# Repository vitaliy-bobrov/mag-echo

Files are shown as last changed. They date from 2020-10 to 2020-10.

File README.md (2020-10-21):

# Mag Echo

Mag Echo delay + modulation based on Keeley Mag Echo.

The repository contains KiCad source files: schematic, PCB, BOM.

## Schematic

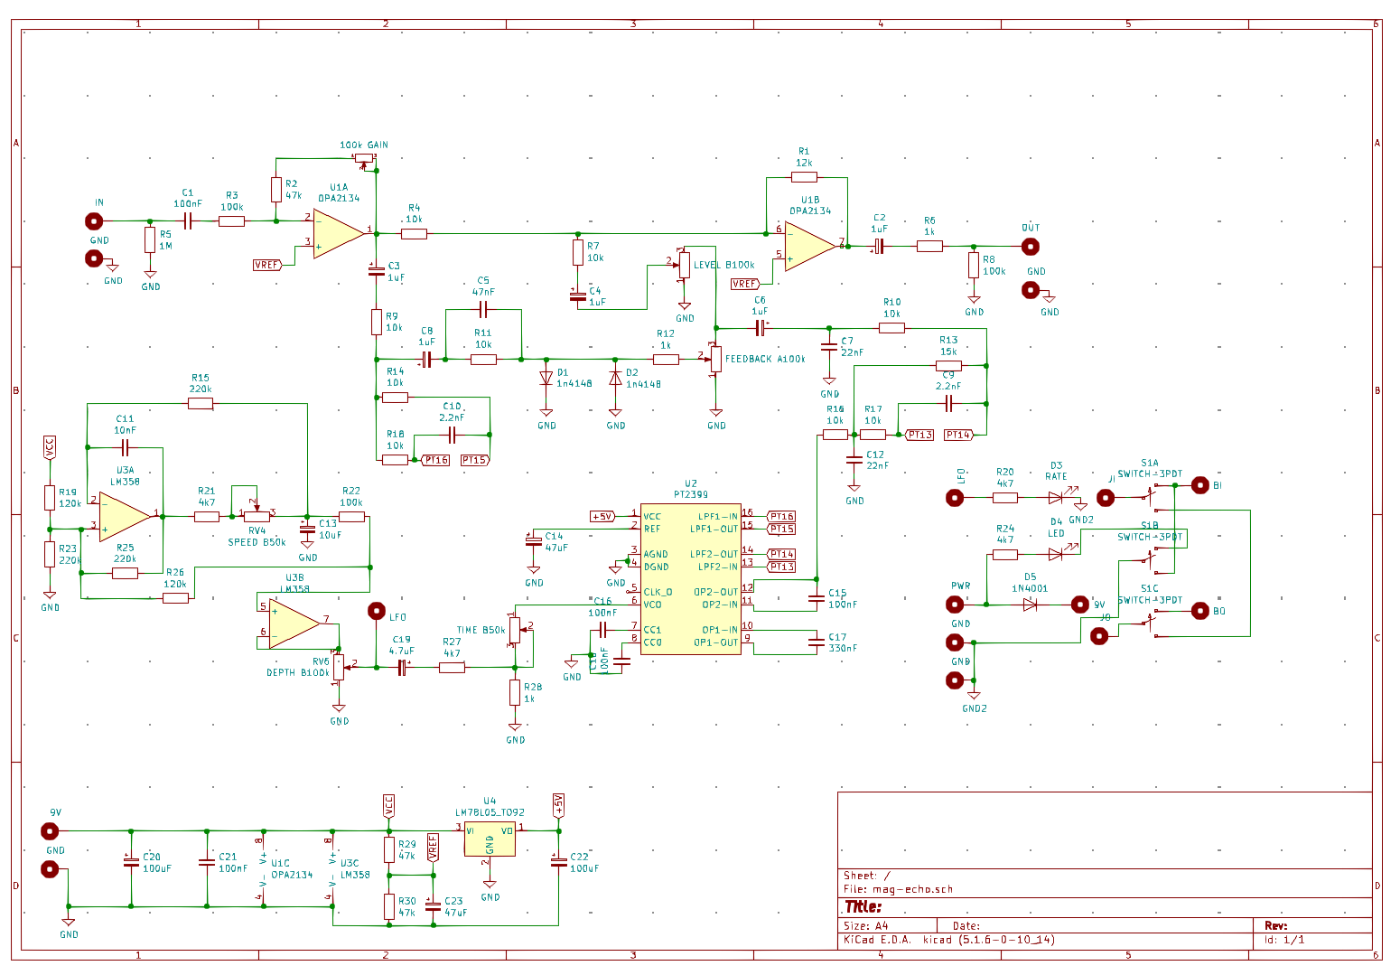
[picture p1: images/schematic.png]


## PCB (3D preview)

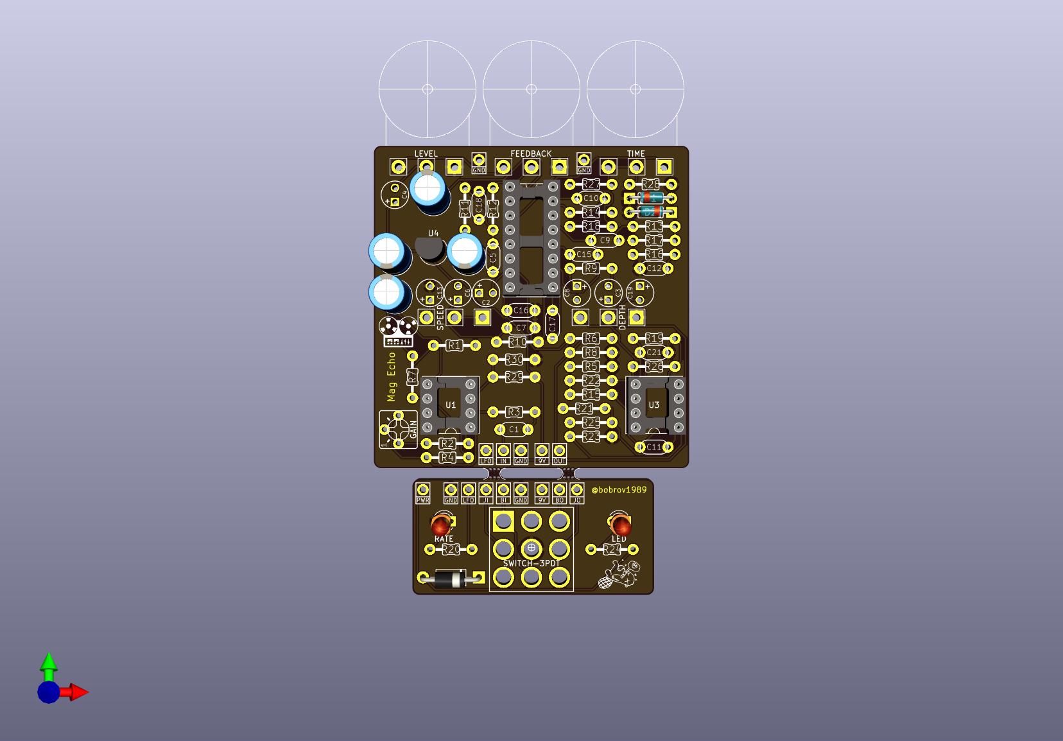
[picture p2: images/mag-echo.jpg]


## Interactive BOM

👉 [BOM](https://vitaliy-bobrov.github.io/mag-echo/)

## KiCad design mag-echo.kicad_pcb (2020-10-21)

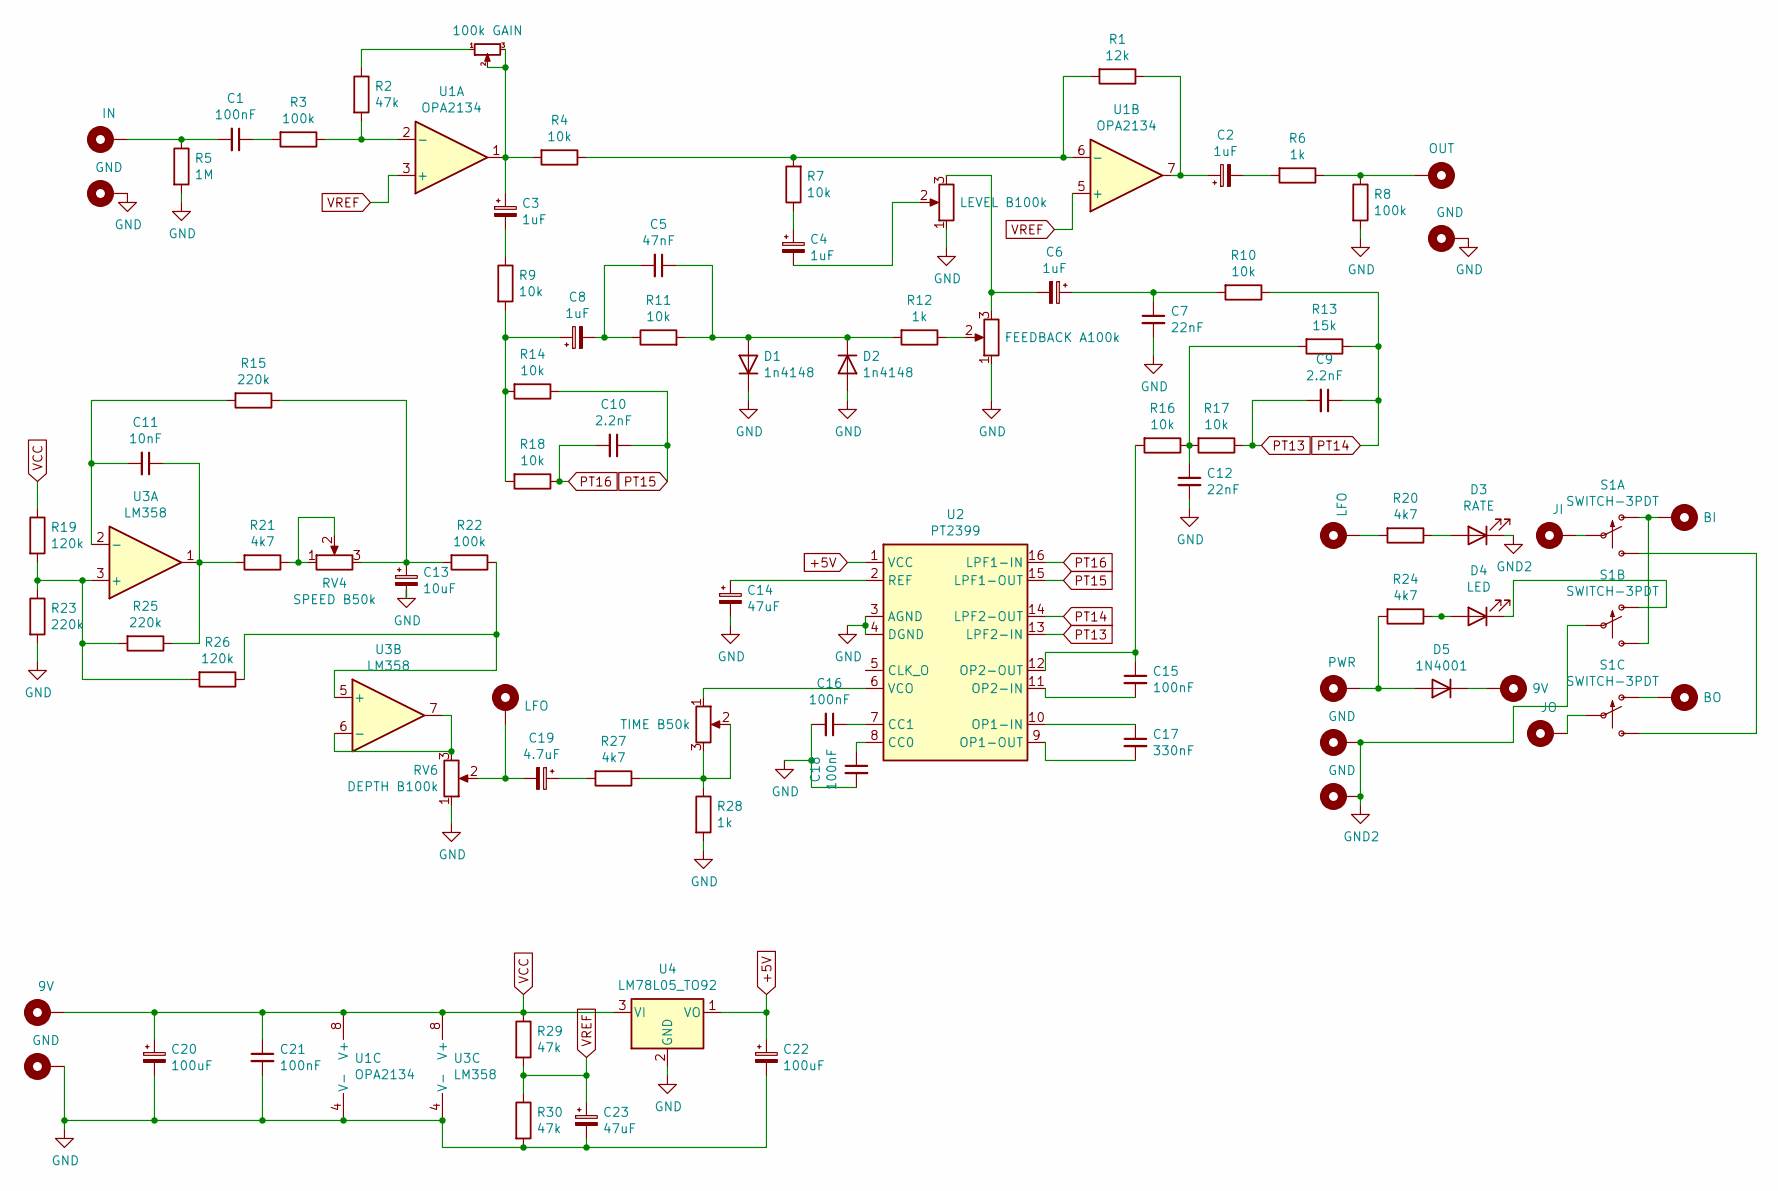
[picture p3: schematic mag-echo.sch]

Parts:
C1, C15, C16, C18, C21: 100nF; 0.2%22.SML
C2, C3, C4, C6, C8: 1uF; 0503
C5: 47nF; 0.2%22.SML
C7, C12: 22nF; 0.2%22.SML
C9, C10: 2.2nF; 0.2%22.SML
C11: 10nF; 0.2%22.SML
C13: 10uF; 0503
C14, C23: 47uF; 0632
C17: 330nF; 0.2%22.SML
C19: 4.7uF; 0503
C20, C22: 100uF; 0632
D1, D2: 1n4148; DO35-3
D3: RATE; LED_D3.0mm
D4: LED; LED_D3.0mm
D5: 1N4001; D_DO-41_SOD81_P10.16mm_Horizontal
H1: IN; PAD1
H2: OUT; PAD1
H3, H4, H13, H14, H16: GND; PAD1
H5: BI; PAD1
H6, H11: LFO; PAD1
H7: JI; PAD1
H8: PWR; PAD1
H9, H15: 9V; PAD1
H10: BO; PAD1
H12: JO; PAD1
R1: 12k; 0.3%22.A
R2, R29, R30: 47k; 0.3%22.A
R3, R8, R22: 100k; 0.3%22.A
R4, R7, R9, R10, R11, R14, R16, R17, R18: 10k; 0.3%22.A
R5: 1M; 0.3%22.A
R6, R12, R28: 1k; 0.3%22.A
R13: 15k; 0.3%22.A
R15, R23, R25: 220k; 0.3%22.A
R19, R26: 120k; 0.3%22.A
R20, R21, R24, R27: 4k7; 0.3%22.A
RV1: 100k GAIN; TRIM1
RV2: LEVEL B100k; 16MM_B.MOUNT
RV3: FEEDBACK A100k; 16MM_B.MOUNT
RV4: SPEED B50k; 16MM_B.MOUNT
RV5: TIME B50k; 16MM_B.MOUNT
RV6: DEPTH B100k; 16MM_B.MOUNT
S1: SWITCH-3PDT; 3PDT.LUGS.SPF
U1: OPA2134; DIP-8_W7.62mm_Socket
U2: PT2399; DIP-16_W7.62mm_Socket
U3: LM358; DIP-8_W7.62mm_Socket
U4: LM78L05_TO92; TO-92_Inline

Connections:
+5V: C22.1, U2.1 (VCC), U4.1 (VO)
GND: C7.2, C12.2, C13.2, C14.2, C16.2, C18.2, C20.2, C21.2, C22.2, C23.2, D1.1 (K), D2.2 (A), H3.1, H4.1, H16.1, R5.2, R8.2, R23.2, R28.2, R30.2, RV2.1, RV3.1, RV6.1, U1.4 (V-), U2.3 (AGND), U2.4 (DGND), U3.4 (V-), U4.2 (GND)
GND2: D3.1 (K), H13.1, H14.1, S1.P$5
unnamed: C1.1, R3.2
unnamed: C1.2, H1.1, R5.1
unnamed: C2.1, R1.1, U1.7
unnamed: C2.2, R6.2
unnamed: C3.1, R4.2, RV1.2, RV1.3, U1.1
unnamed: C3.2, R9.1
unnamed: C4.1, R7.1
unnamed: C4.2, RV2.2
unnamed: C5.1, D1.2 (A), D2.1 (K), R11.2, R12.2
unnamed: C5.2, C8.2, R11.1
unnamed: C6.1, C7.1, R10.2
unnamed: C6.2, RV2.3, RV3.3
unnamed: C8.1, R9.2, R14.2, R18.2
unnamed: C11.1, R21.2, R25.1, U3.1
unnamed: C11.2, R15.2, U3.2 (-)
unnamed: C12.1, R13.2, R16.1, R17.2
unnamed: C13.1, R15.1, R22.2, RV4.3
unnamed: C14.1, U2.2 (REF)
unnamed: C15.1, R16.2, U2.12 (OP2-OUT)
unnamed: C15.2, U2.11 (OP2-IN)
unnamed: C16.1, U2.7 (CC1)
unnamed: C17.1, U2.10 (OP1-IN)
unnamed: C17.2, U2.9 (OP1-OUT)
unnamed: C18.1, U2.8 (CC0)
unnamed: C19.1, R27.2
unnamed: C19.2, H11.1, RV6.2
unnamed: D3.2 (A), R20.1
unnamed: D4.1 (K), S1.P$4 (O)
unnamed: D4.2 (A), R24.1
unnamed: D5.1 (K), H9.1
unnamed: D5.2 (A), H8.1, R24.2
unnamed: H2.1, R6.1, R8.1
unnamed: H5.1, S1.P$1 (O), S1.P$6 (S)
unnamed: H6.1, R20.2
unnamed: H7.1, S1.P$2
unnamed: H10.1, S1.P$7 (O)
unnamed: H12.1, S1.P$8
unnamed: R1.2, R4.1, R7.2, U1.6 (-)
unnamed: R2.1, RV1.1
unnamed: R2.2, R3.1, U1.2 (-)
unnamed: R12.1, RV3.2
unnamed: R19.2, R23.1, R25.2, R26.2, U3.3 (+)
unnamed: R21.1, RV4.1, RV4.2
unnamed: R22.1, R26.1, U3.5 (+)
unnamed: R27.1, R28.1, RV5.2, RV5.3
unnamed: RV5.1, U2.6 (VCO)
unnamed: RV6.3, U3.6 (-), U3.7
unnamed: S1.P$3 (S), S1.P$9 (S)
PT13: C9.2, R17.1, U2.13 (LPF2-IN)
PT14: C9.1, R10.1, R13.1, U2.14 (LPF2-OUT)
PT15: C10.1, R14.1, U2.15 (LPF1-OUT)
PT16: C10.2, R18.1, U2.16 (LPF1-IN)
VCC: C20.1, C21.1, H15.1, R19.1, R29.1, U1.8 (V+), U3.8 (V+), U4.3 (VI)
VREF: C23.1, R29.2, R30.1, U1.3 (+), U1.5 (+)

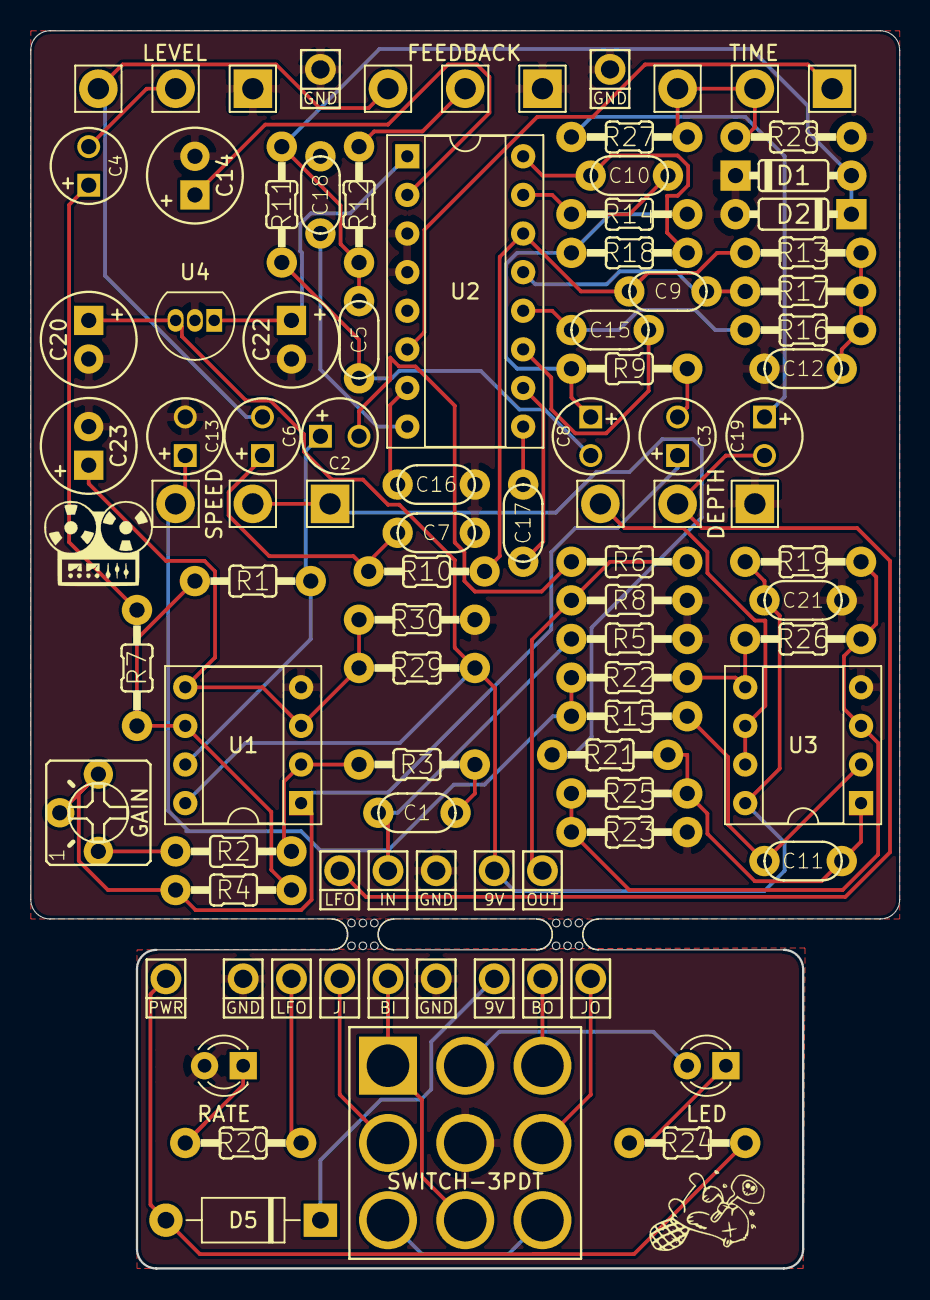
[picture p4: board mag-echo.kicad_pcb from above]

Board: 2 copper layers, 57.2 x 81.4 mm, 90 parts (0 on the bottom side), 57 nets.

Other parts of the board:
JOUT4, JOUT4#2: LUMBURG_DRILL
Ref**: Val**; DC_TOP
mouse-bite-2mm-slot, mouse-bite-2mm-slot#2: VAL**; mouse-bite-2mm-slot
